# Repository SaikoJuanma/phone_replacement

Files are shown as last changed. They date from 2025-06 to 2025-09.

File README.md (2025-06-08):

this projects aims to create a replacement for the phone, so I can stop using my phone on the home and get rid off distractions.
## Upcoming features
1. Timer and alarm.
2. PCB and schematics for the project.
3. 3D desings for the project.

When the project makes progress help will be included on how to set it up, how to print, etc.
New features will be revised when all the previous ones are met.

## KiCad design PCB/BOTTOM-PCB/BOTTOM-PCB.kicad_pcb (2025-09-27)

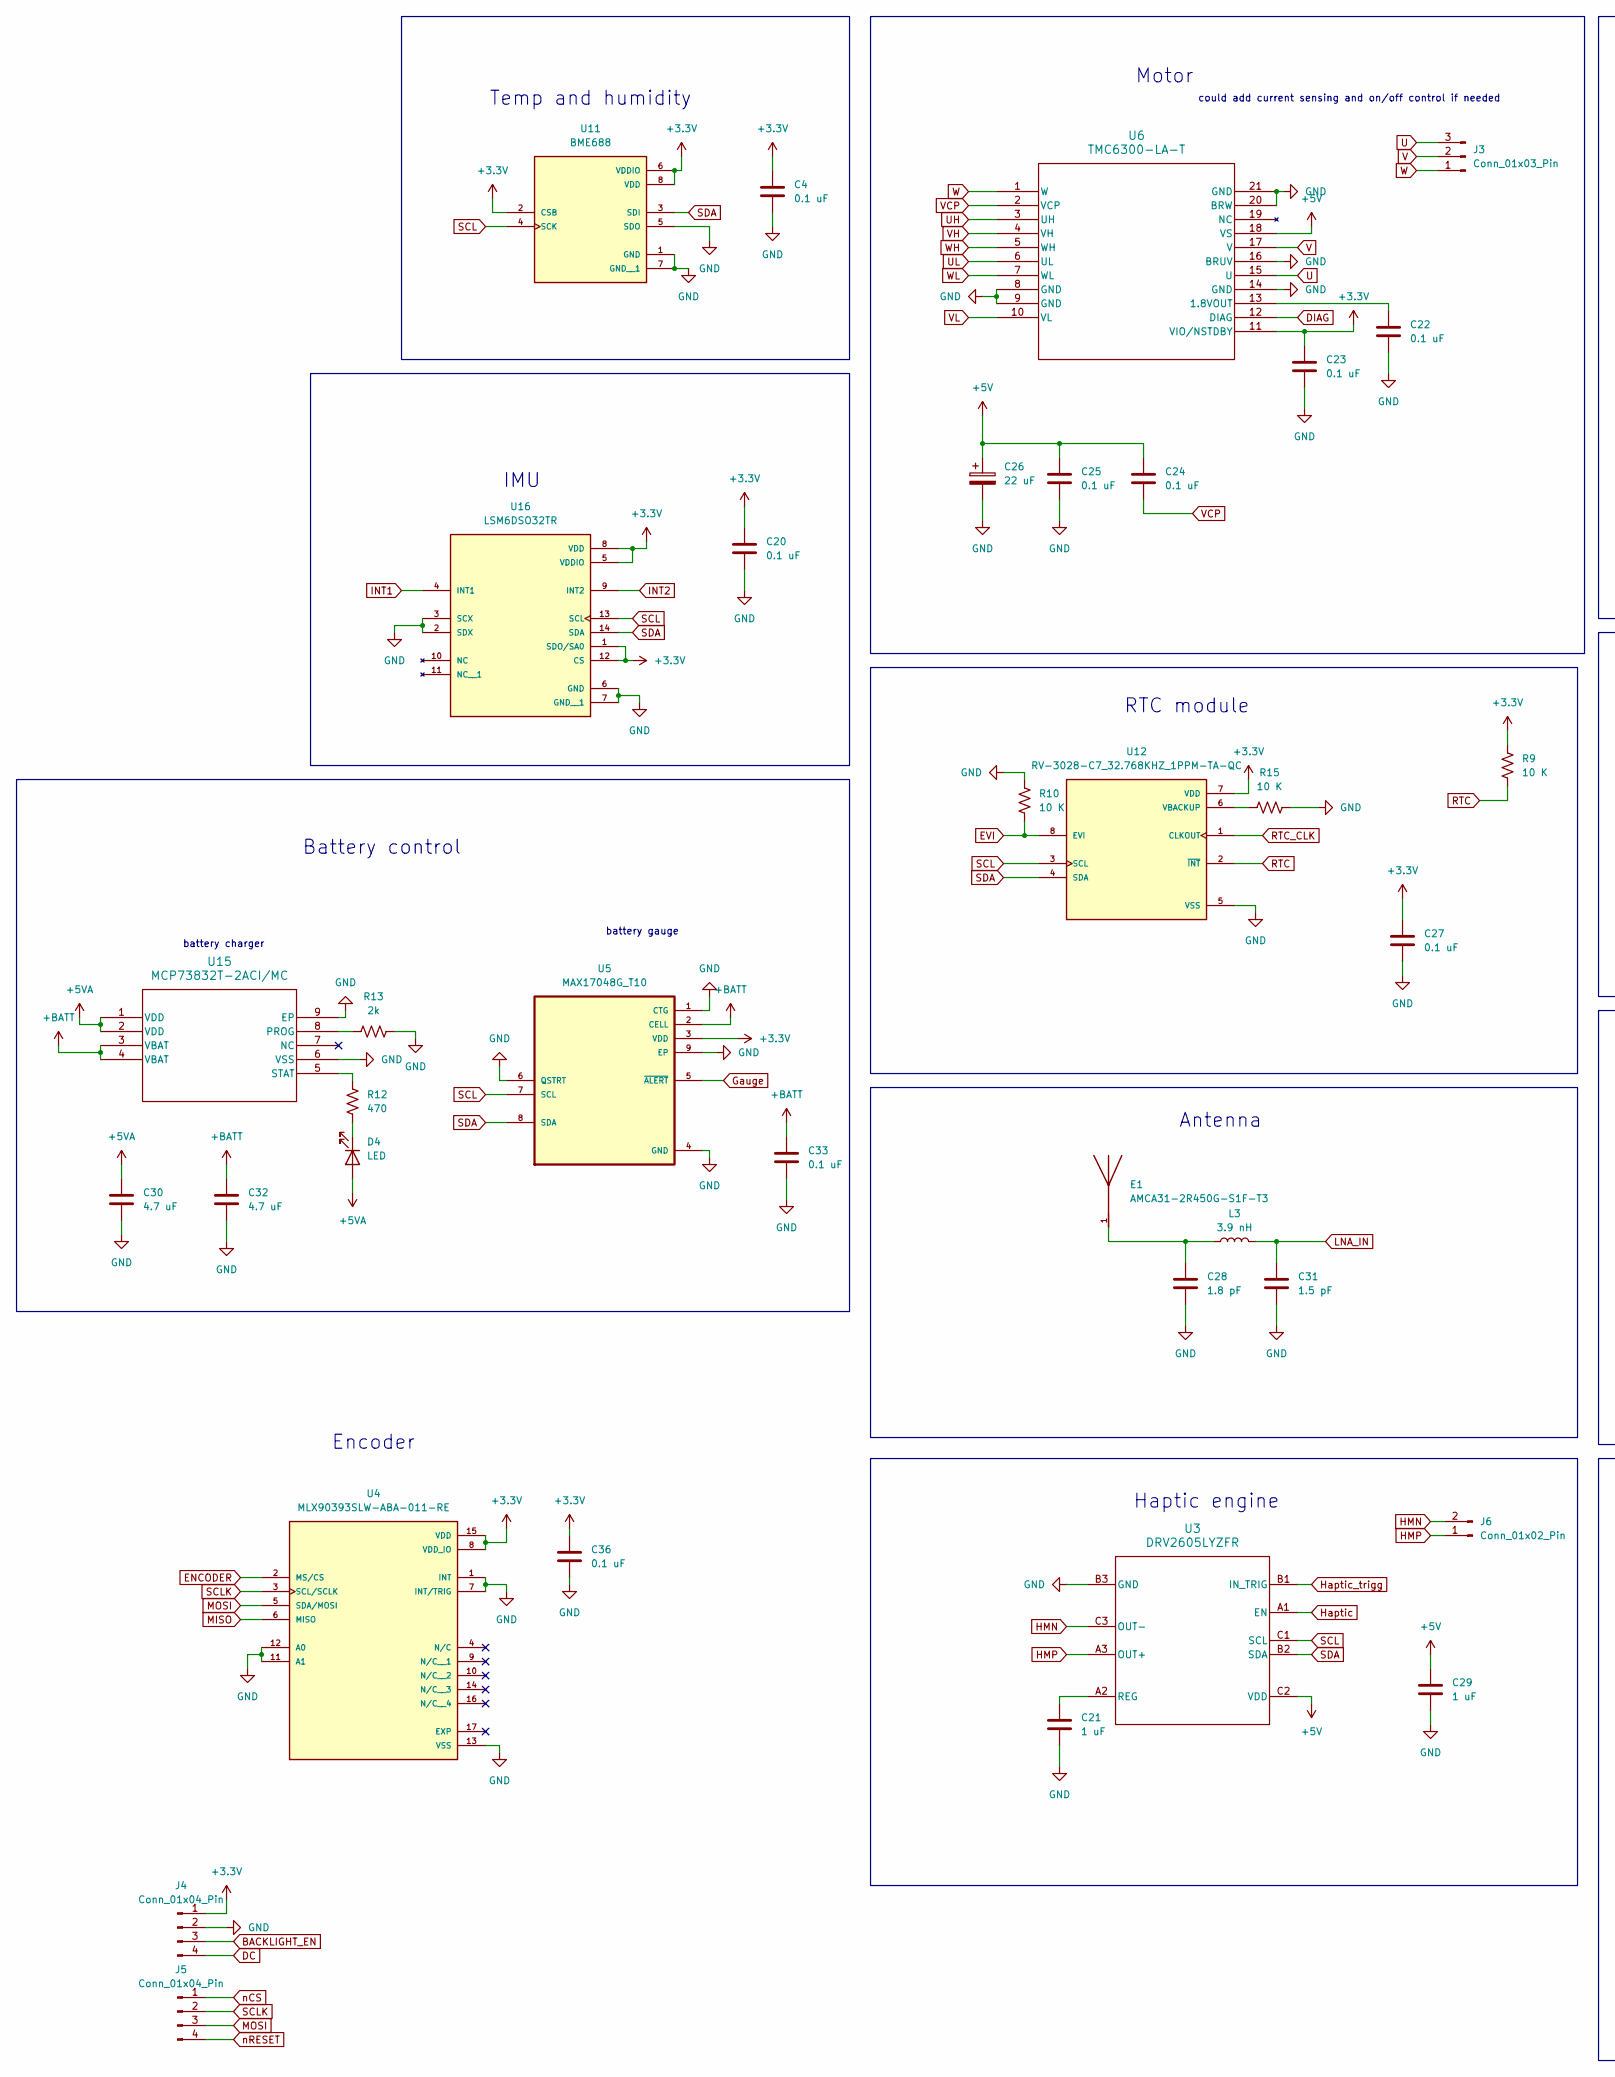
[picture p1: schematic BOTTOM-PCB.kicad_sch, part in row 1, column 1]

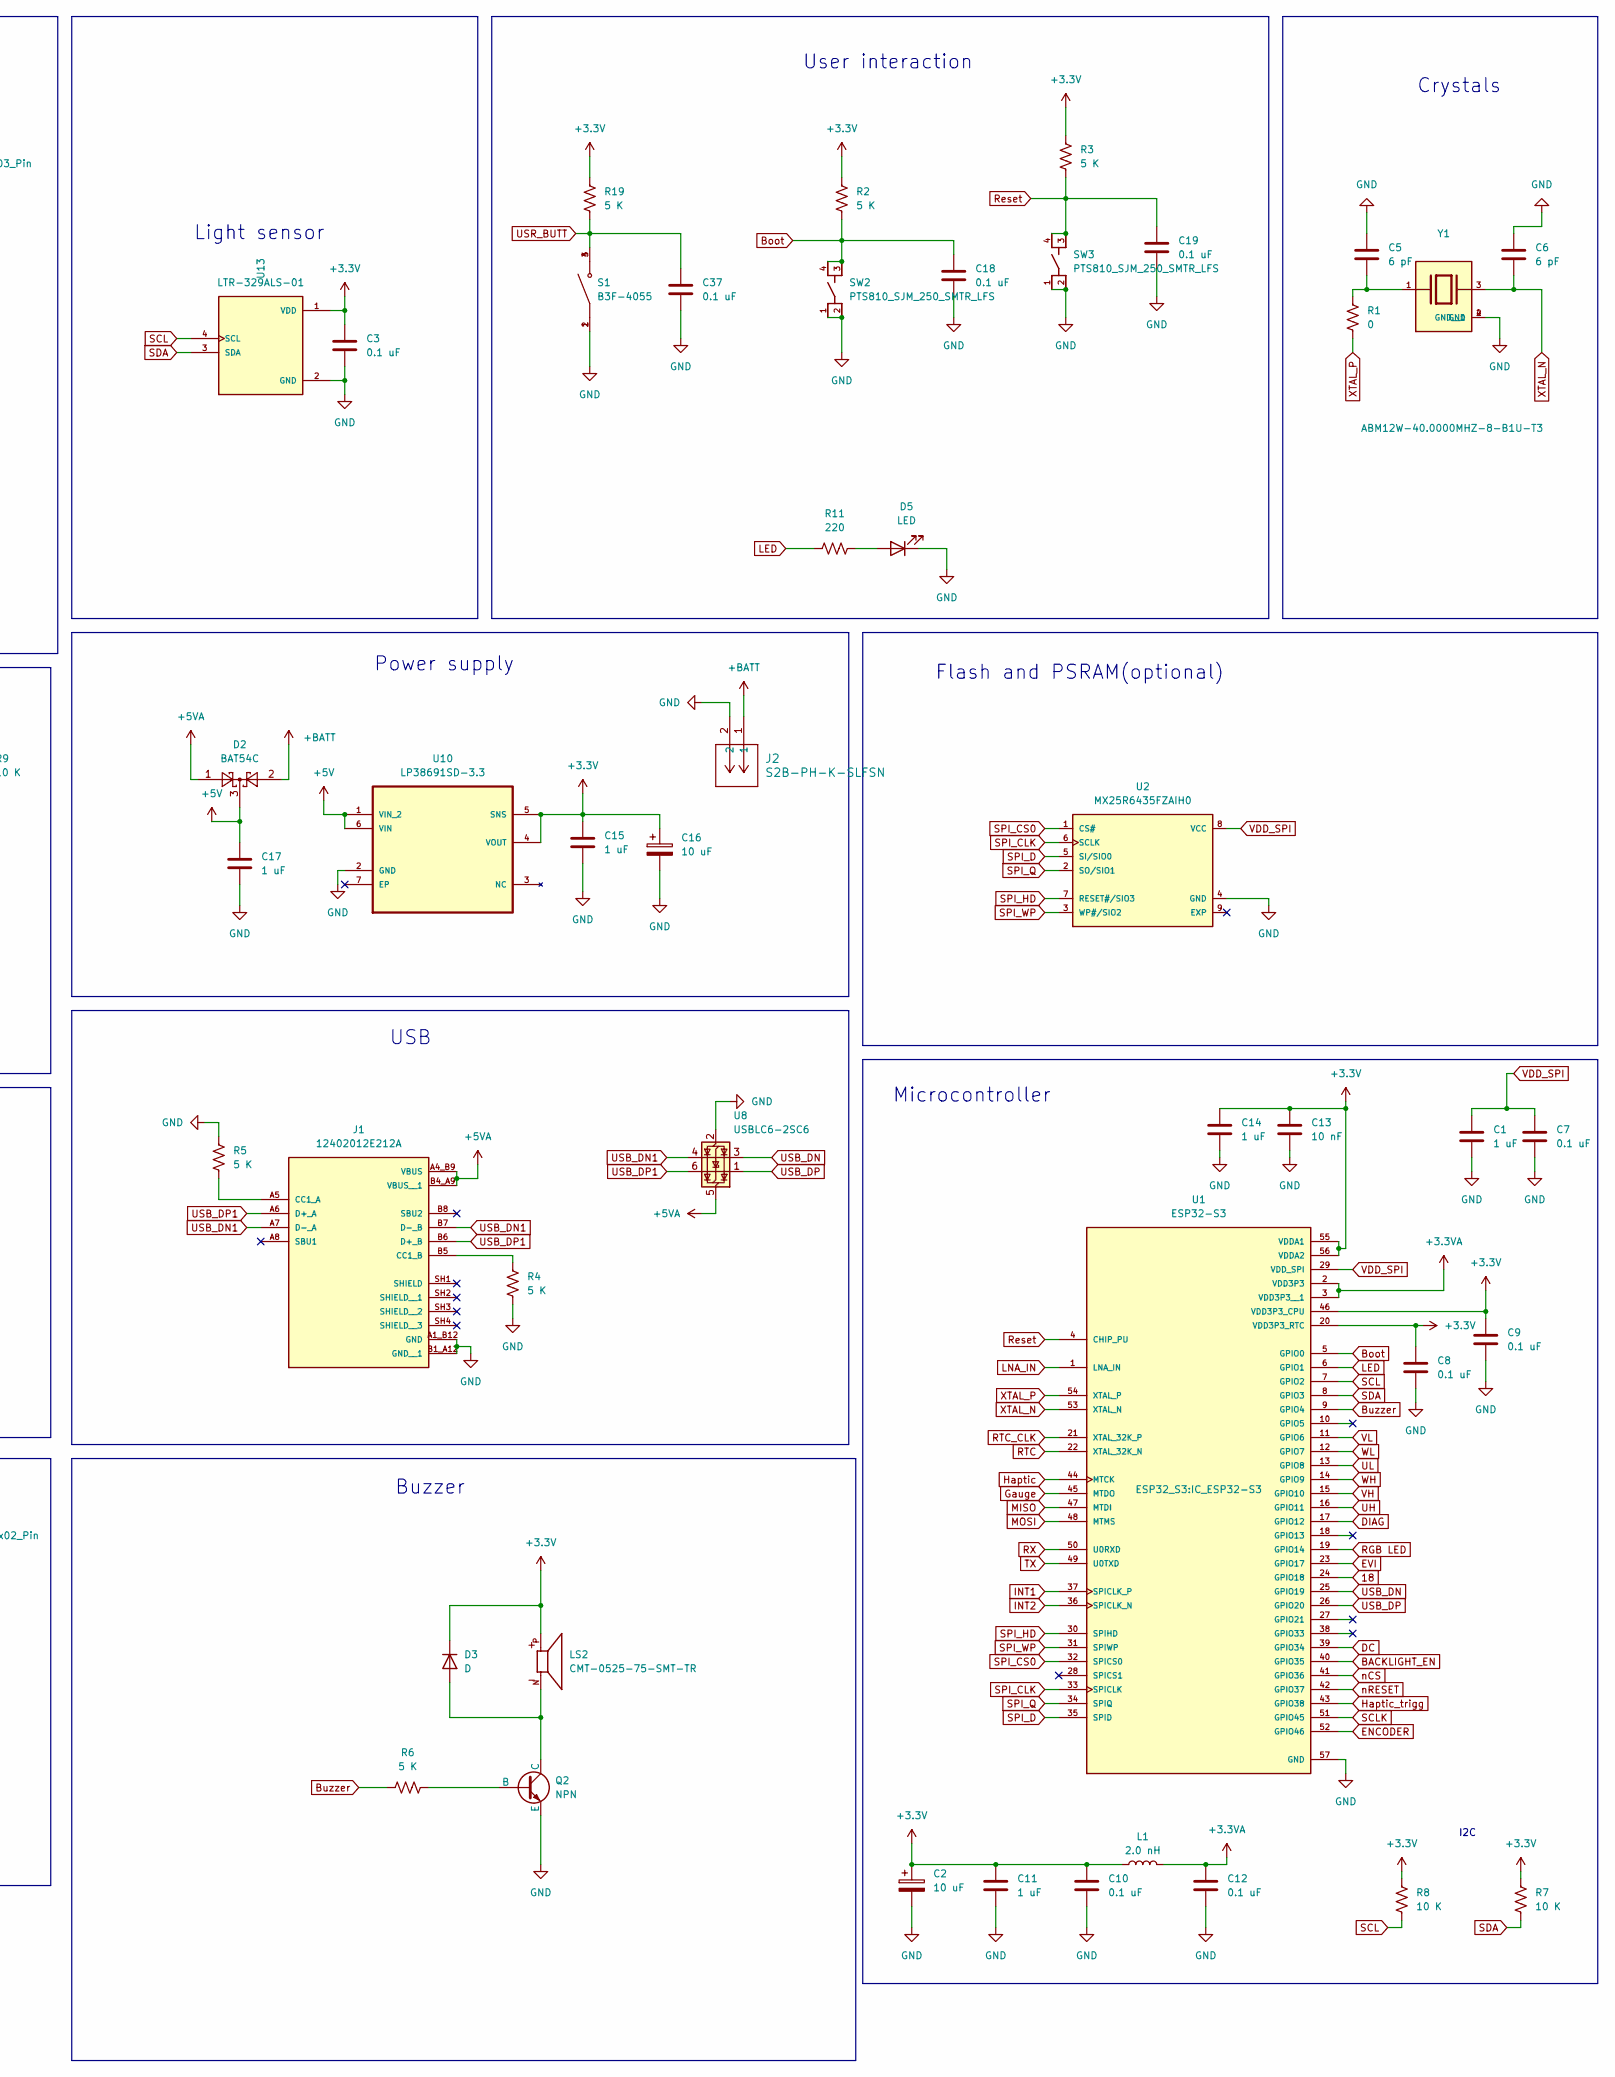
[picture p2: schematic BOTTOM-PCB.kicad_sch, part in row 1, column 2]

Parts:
C1, C11, C14, C15, C17, C21, C29: 1 uF; C_0402_1005Metric_Pad0.74x0.62mm_HandSolder
C2, C16: 10 uF; CP_EIA-1608-08_AVX-J_HandSolder
C3, C4, C7, C8, C9, C10, C12, C18, C19, C20, C22, C23, C24, C25, C27, C33, C36, C37: 0.1 uF; C_0402_1005Metric_Pad0.74x0.62mm_HandSolder
C5, C6: 6 pF; C_0402_1005Metric_Pad0.74x0.62mm_HandSolder
C13: 10 nF; C_0402_1005Metric_Pad0.74x0.62mm_HandSolder
C26: 22 uF; CP_EIA-1608-08_AVX-J_HandSolder
C28: 1.8 pF; C_0201_0603Metric_Pad0.64x0.40mm_HandSolder
C30, C32: 4.7 uF; C_0402_1005Metric_Pad0.74x0.62mm_HandSolder
C31: 1.5 pF; C_0201_0603Metric_Pad0.64x0.40mm_HandSolder
D2: BAT54C; SOT-23
D3: D; D_0402_1005Metric_Pad0.77x0.64mm_HandSolder
D4, D5: LED; LED_0805_2012Metric
E1: AMCA31-2R450G-S1F-T3; XDCR_AMCA31-2R450G-S1F-T3; PARTREV 03-21-19
J1: 12402012E212A; AMPHENOL_12402012E212A; PARTREV 4
J2: S2B-PH-K-SLFSN; JST_ZH_B2B-ZR_1x02_P1.50mm_Vertical
J3: Conn_01x03_Pin; JST_ZH_B3B-ZR_1x03_P1.50mm_Vertical
J4, J5: Conn_01x04_Pin; PinHeader_1x04_P1.27mm_Vertical
J6: Conn_01x02_Pin; JST_ZH_B2B-ZR_1x02_P1.50mm_Vertical
L1: 2.0 nH; L_0402_1005Metric_Pad0.77x0.64mm_HandSolder
L3: 3.9 nH; L_0201_0603Metric_Pad0.64x0.40mm_HandSolder
LS2: CMT-0525-75-SMT-TR; XDCR_CMT-0525-75-SMT-TR; PARTREV 1.0
Q2: NPN; SOT-723
R1: 0; R_0402_1005Metric_Pad0.72x0.64mm_HandSolder
R2, R3, R4, R5, R6, R19: 5 K; R_0402_1005Metric_Pad0.72x0.64mm_HandSolder
R7, R8, R9, R10, R15: 10 K; R_0402_1005Metric_Pad0.72x0.64mm_HandSolder
R11: 220; R_0402_1005Metric_Pad0.72x0.64mm_HandSolder
R12: 470; R_0402_1005Metric_Pad0.72x0.64mm_HandSolder
R13: 2k; R_0402_1005Metric_Pad0.72x0.64mm_HandSolder
S1: B3F-4055; SW_B3F-4055; PARTREV A070-E1-08
SW2, SW3: PTS810_SJM_250_SMTR_LFS; SW_PTS810_SJM_250_SMTR_LFS
U1: ESP32-S3; IC_ESP32-S3; PARTREV v1.2
U2: MX25R6435FZAIH0; SON80P400X400X60-9N
U3: DRV2605LYZFR; YZF0009ADAD
U4: MLX90393SLW-ABA-011-RE; QFN50P300X300X100-17N; PARTREV 010
U5: MAX17048G_T10; SON50P200X200X80-9N
U6: TMC6300-LA-T; 21-100586_K2033&plus_1C_ADI-M; MPN 175-TMC6300-LA-TCT-ND
U8: USBLC6-2SC6; SOT-23-6
U10: LP38691SD-3.3; DFN300X300X80-7N; MPN LP38691SD-3.3
U11: BME688; IC_BME688; PARTREV 1.0
U12: RV-3028-C7_32.768KHZ_1PPM-TA-QC; MicroCrystal_C7_SON-8_1.5x3.2mm_P0.9mm; PARTREV 1.3
U13: LTR-329ALS-01; IC_LTR-329ALS-01; PARTREV 1.8
U15: MCP73832T-2ACI/MC; DFN8_2x3MC_MCH-L
U16: LSM6DSO32TR; XDCR_LSM6DSO32TR; PARTREV 1
Y1: ABM12W-40.0000MHZ-8-B1U-T3; XTAL_ABM12W-40.0000MHZ-8-B1U-T3; PARTREV 10.05.2020

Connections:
18: U1.24 (GPIO18)
+3.3V: C2.1, C3.1, C4.1, C8.1, C9.1, C10.1, C11.1, C13.1, C14.1, C15.1, C16.1, C20.1, C23.1, C27.2, C36.2, D3.1 (K), J4.1, L1.1, LS2.P, R2.1, R3.1, R7.2, R8.2, R9.2, R19.1, U1.20 (VDD3P3_RTC), U1.46 (VDD3P3_CPU), U1.55 (VDDA1), U1.56 (VDDA2), U4.8 (VDD_IO), U4.15 (VDD), U5.3 (VDD), U6.11 (VIO/NSTDBY), U10.4 (VOUT), U10.5 (SNS), U11.2 (CSB), U11.6 (VDDIO), U11.8 (VDD), U12.7 (VDD), U13.1 (VDD), U16.1 (SDO/SA0), U16.5 (VDDIO), U16.8 (VDD), U16.12 (CS)
+3.3VA: C12.1, L1.2, U1.2 (VDD3P3), U1.3 (VDD3P3__1)
+5V: C17.1, C24.1, C25.1, C26.1, C29.2, D2.3, U3.C2 (VDD), U6.18 (VS), U10.1 (VIN_2), U10.6 (VIN)
+5VA: C30.2, D2.1, D4.2 (A), J1.A4_B9 (VBUS), J1.B4_A9 (VBUS__1), U8.5 (VBUS), U15.1 (VDD), U15.2 (VDD)
+BATT: C32.2, C33.2, D2.2, J2.1, U5.2 (CELL), U15.3 (VBAT), U15.4 (VBAT)
BACKLIGHT_EN: J4.3, U1.40 (GPIO35)
Boot: C18.1, R2.2, SW2.3, SW2.4, U1.5 (GPIO0)
Buzzer: R6.2, U1.9 (GPIO4)
DC: J4.4, U1.39 (GPIO34)
DIAG: U1.17 (GPIO12), U6.12 (DIAG)
ENCODER: U1.52 (GPIO46), U4.2 (MS/CS)
EVI: R10.2, U1.23 (GPIO17), U12.8 (EVI)
GND: C1.2, C2.2, C3.2, C4.2, C5.1, C6.1, C7.2, C8.2, C9.2, C10.2, C11.2, C12.2, C13.2, C14.2, C15.2, C16.2, C17.2, C18.2, C19.2, C20.2, C21.1, C22.2, C23.2, C25.2, C26.2, C27.1, C28.1, C29.1, C30.1, C31.1, C32.1, C33.1, C36.1, C37.2, D5.1 (K), J1.A1_B12 (GND), J1.B1_A12 (GND__1), J2.2, J4.2, Q2.3 (E), R4.2, R5.1, R10.1, R13.2, R15.2, S1.1, S1.2, SW2.1, SW2.2, SW3.1, SW3.2, U1.57 (GND), U2.4 (GND), U3.B3 (GND), U4.1 (INT), U4.7 (INT/TRIG), U4.11 (A1), U4.12 (A0), U4.13 (VSS), U5.1 (CTG), U5.4 (GND), U5.6 (QSTRT), U5.9 (EP), U6.8 (GND), U6.9 (GND), U6.14 (GND), U6.16 (BRUV), U6.20 (BRW), U6.21 (GND), U8.2 (GND), U10.2 (GND), U11.1 (GND), U11.5 (SDO), U11.7 (GND__1), U12.5 (VSS), U13.2 (GND), U15.6 (VSS), U15.9 (EP), U16.2 (SDX), U16.3 (SCX), U16.6 (GND), U16.7 (GND__1), Y1.2 (GND), Y1.4 (GND__1)
Gauge: U1.45 (MTDO), U5.5 (~ALERT)
HMN: J6.2, U3.C3 (OUT-)
HMP: J6.1, U3.A3 (OUT+)
Haptic: U1.44 (MTCK), U3.A1 (EN)
Haptic_trigg: U1.43 (GPIO38), U3.B1 (IN_TRIG)
INT1: U1.37 (SPICLK_P), U16.4 (INT1)
INT2: U1.36 (SPICLK_N), U16.9 (INT2)
LED: R11.1, U1.6 (GPIO1)
LNA_IN: C31.2, L3.2, U1.1 (LNA_IN)
MISO: U1.47 (MTDI), U4.6 (MISO)
MOSI: J5.3, U1.48 (MTMS), U4.5 (SDA/MOSI)
unnamed: C5.2, R1.1, Y1.1
unnamed: C28.2, E1.1, L3.1
unnamed: D3.2 (A), LS2.N, Q2.1 (C)
unnamed: D4.1 (K), R12.2
unnamed: D5.2 (A), R11.2
unnamed: J1.A5 (CC1_A), R5.2
unnamed: J1.B5 (CC1_B), R4.1
unnamed: Q2.2 (B), R6.1
unnamed: C21.2, U3.A2 (REG)
unnamed: C22.1, U6.13 (1.8VOUT)
unnamed: R15.1, U12.6 (VBACKUP)
unnamed: R13.1, U15.8 (PROG)
unnamed: R12.1, U15.5 (STAT)
RGB LED: U1.19 (GPIO14)
RTC: R9.1, U1.22 (XTAL_32K_N), U12.2 (~INT)
RTC_CLK: U1.21 (XTAL_32K_P), U12.1 (CLKOUT)
RX: U1.50 (U0RXD)
Reset: C19.1, R3.2, SW3.3, SW3.4, U1.4 (CHIP_PU)
SCL: R8.1, U1.7 (GPIO2), U3.C1 (SCL), U5.7 (SCL), U11.4 (SCK), U12.3 (SCL), U13.4 (SCL), U16.13 (SCL)
SCLK: J5.2, U1.51 (GPIO45), U4.3 (SCL/SCLK)
SDA: R7.1, U1.8 (GPIO3), U3.B2 (SDA), U5.8 (SDA), U11.3 (SDI), U12.4 (SDA), U13.3 (SDA), U16.14 (SDA)
SPI_CLK: U1.33 (SPICLK), U2.6 (SCLK)
SPI_CS0: U1.32 (SPICS0), U2.1 (CS#)
SPI_D: U1.35 (SPID), U2.5 (SI/SIO0)
SPI_HD: U1.30 (SPIHD), U2.7 (RESET#/SIO3)
SPI_Q: U1.34 (SPIQ), U2.2 (SO/SIO1)
SPI_WP: U1.31 (SPIWP), U2.3 (WP#/SIO2)
TX: U1.49 (U0TXD)
U: J3.3, U6.15 (U)
UH: U1.16 (GPIO11), U6.3 (UH)
UL: U1.13 (GPIO8), U6.6 (UL)
USB_DN: U1.25 (GPIO19), U8.3 (I/O2)
USB_DN1: J1.A7 (D-_A), J1.B7 (D-_B), U8.4 (I/O2)
USB_DP: U1.26 (GPIO20), U8.1 (I/O1)
USB_DP1: J1.A6 (D+_A), J1.B6 (D+_B), U8.6 (I/O1)
USR_BUTT: C37.1, R19.2, S1.3, S1.4
V: J3.2, U6.17 (V)
VCP: C24.2, U6.2 (VCP)
VDD_SPI: C1.1, C7.1, U1.29 (VDD_SPI), U2.8 (VCC)
VH: U1.15 (GPIO10), U6.4 (VH)
VL: U1.11 (GPIO6), U6.10 (VL)
W: J3.1, U6.1 (W)
WH: U1.14 (GPIO9), U6.5 (WH)
WL: U1.12 (GPIO7), U6.7 (WL)
XTAL_N: C6.2, U1.53 (XTAL_N), Y1.3
XTAL_P: R1.2, U1.54 (XTAL_P)
nCS: J5.1, U1.41 (GPIO36)
nRESET: J5.4, U1.42 (GPIO37)

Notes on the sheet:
Antenna
Crystals
Motor
Flash and PSRAM(optional)
Encoder
could add current sensing and on/off control if needed
Microcontroller
Power supply
I2C
Temp and humidity
IMU
Haptic engine
Battery control
Light sensor
User interaction
battery gauge
battery charger
USB
RTC module
Buzzer

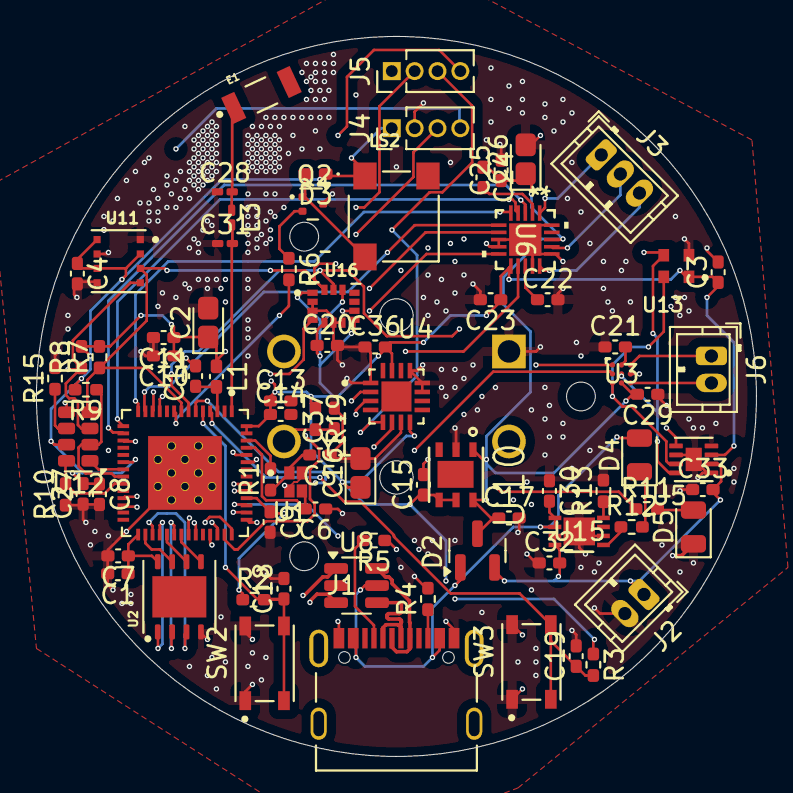
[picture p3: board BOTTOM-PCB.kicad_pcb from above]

Board: 4 copper layers, 40.0 x 40.0 mm, 82 parts (1 on the bottom side), 69 nets.

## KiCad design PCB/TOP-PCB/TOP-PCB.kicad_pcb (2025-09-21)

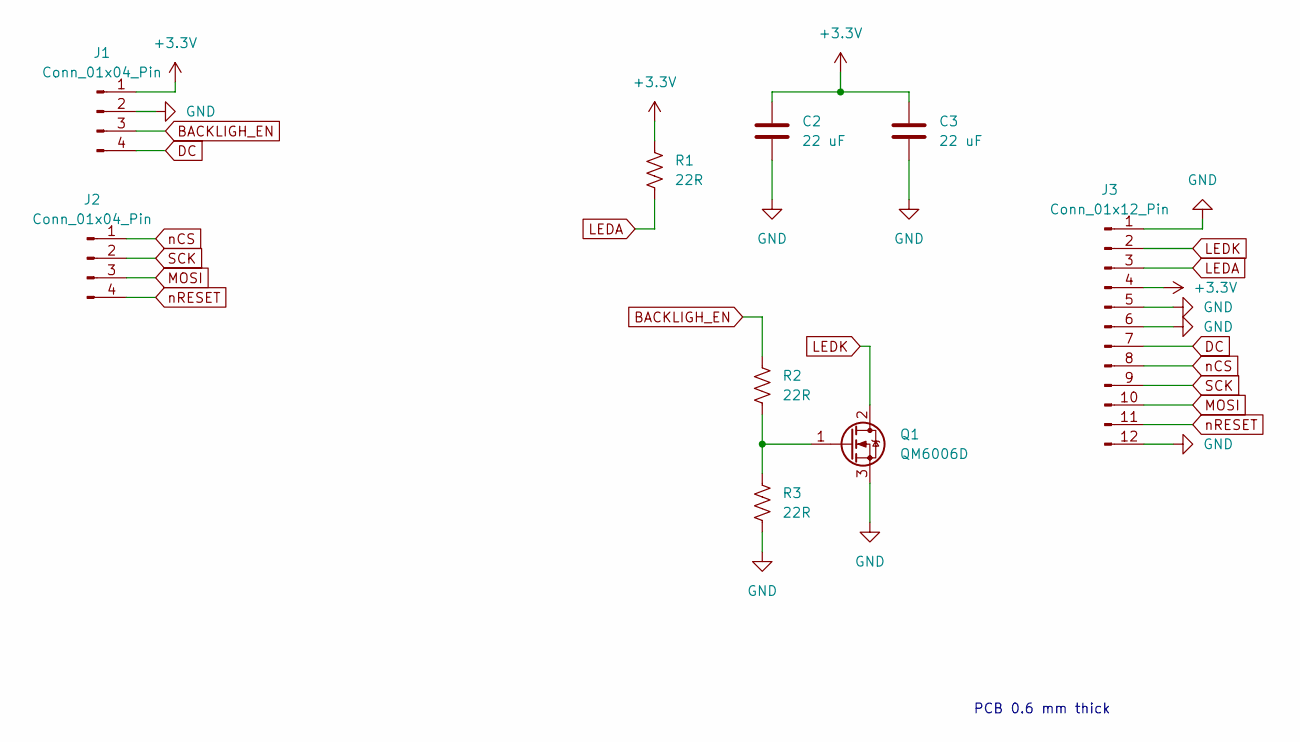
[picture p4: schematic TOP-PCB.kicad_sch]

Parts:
C2, C3: 22 uF; C_0201_0603Metric_Pad0.64x0.40mm_HandSolder
J1, J2: Conn_01x04_Pin; PinHeader_1x04_P1.27mm_Vertical
J3: Conn_01x12_Pin; GC9A01Round1.28
Q1: QM6006D; TO-252-2
R1, R2, R3: 22R; R_0201_0603Metric_Pad0.64x0.40mm_HandSolder

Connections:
+3.3V: C2.1, C3.1, J1.1, J3.4, R1.1
BACKLIGH_EN: J1.3, R2.1
DC: J1.4, J3.7
GND: C2.2, C3.2, J1.2, J3.1, J3.5, J3.6, J3.12, Q1.3 (S), R3.2
LEDA: J3.3, R1.2
LEDK: J3.2, Q1.2 (D)
MOSI: J2.3, J3.10
unnamed: Q1.1 (G), R2.2, R3.1
SCK: J2.2, J3.9
nCS: J2.1, J3.8
nRESET: J2.4, J3.11

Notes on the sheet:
PCB 0.6 mm thick

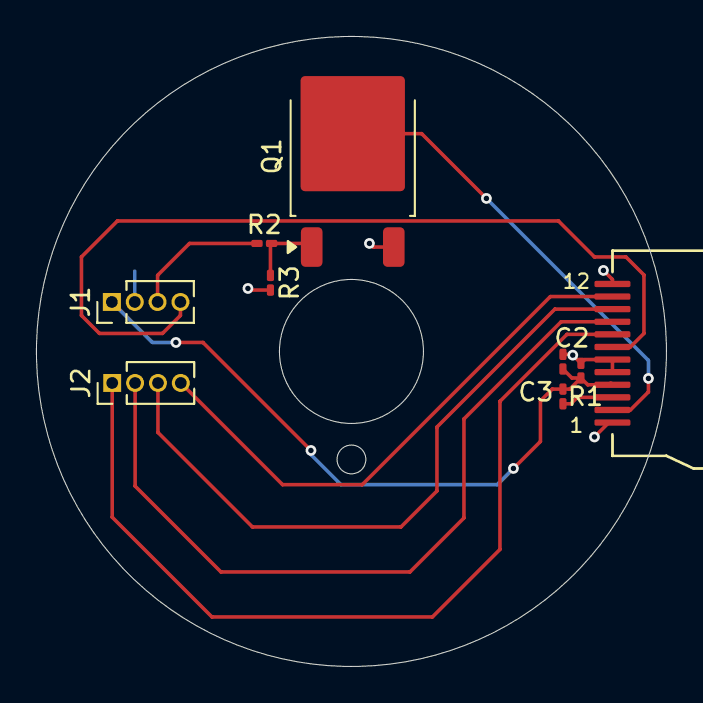
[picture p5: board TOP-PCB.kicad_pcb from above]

Board: 2 copper layers, 35.0 x 35.0 mm, 9 parts (0 on the bottom side), 11 nets.

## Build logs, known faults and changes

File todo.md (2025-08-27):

# Things to do on the project
- [ ] Make a working clock to keep track of time
- [ ] Add apropriate clang format to the project
- [ ] Add gitignore (include things for the pcb too)
- [ ] Fix virtual environment issue
- [ ] Deps should be inside of timer alarm not  inside git

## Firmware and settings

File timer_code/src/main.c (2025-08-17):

#include <zephyr/kernel.h>
#include <zephyr/device.h>
#include <zephyr/drivers/gpio.h>
#include <zephyr/usb/usb_device.h>

const struct device *dev = DEVICE_DT_GET(DT_CHOSEN(zephyr_console));

int main(void)
{
    if (!device_is_ready(dev)) {
        printk("Device not ready\n");
        return -1;
    }

    // INFO: only necessary with adafruit
    if (usb_enable(NULL)) {
        printk("USB enable failed\n");
        return -1;
    }

    printk("This is the encoder sample code!\n");
    while (1) {
        k_sleep(K_SECONDS(3));
        printk("This is the encoder sample code!\n");
    }
}

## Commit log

2025-08-24 PCB files added, first version not ready
    [12402012E212A.step, ABS07-32.768KHZ-T.step, CX2016DB40000D0FLJCC.step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]
2025-08-25 schematic almost ready
    [21-100586_K20331C_ADI.step, CONMHF1-SMD-T.step, MCP7940MT-I_SN.step]
2025-08-26 more pcb changes, schematic ready, now footprint
    [2659.step, ASMB-KTF0-0A306.step, DRV2605LDGSR.step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]
2025-08-27 first vesrion of pcb ready
    [PCB.kicad_pcb, PCB.kicad_sch]
2025-08-29 last changes for the pcb
    [AMCA31-2R450G-S1F-T3.step, BME688.step, BQ27427YZFR.step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]
2025-08-31 new pcb added
    [12402012E212A.step, 21-100586_K20331C_ADI.step, 2659.step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]
2025-09-01 finally git ignore corected
    [BOTTOM-PCB.kicad_pcb, BOTTOM-PCB.kicad_sch, TOP-PCB.kicad_pcb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]
2025-09-15 re organization of top and bottom pcb
    [BOTTOM-PCB.kicad_pcb, BOTTOM-PCB.kicad_sch, TOP-PCB.kicad_pcb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]
2025-09-21 TOP-PCB ready
    [TOP-PCB.kicad_pcb]
2025-09-21 start routing on bottom pcb
    [BOTTOM-PCB.kicad_pcb, BOTTOM-PCB.kicad_sch]
2025-09-22 connections for bottom pcb
    [BOTTOM-PCB.kicad_pcb, BOTTOM-PCB.kicad_sch]
2025-09-24 things to improve
    [BOTTOM-PCB.kicad_pcb, BOTTOM-PCB.kicad_sch]
2025-09-27 I think its ready again
    [BOTTOM-PCB.kicad_pcb, BOTTOM-PCB.kicad_sch]
2025-09-28 starting to add MPN
    [BOTTOM-PCB.kicad_sch]
